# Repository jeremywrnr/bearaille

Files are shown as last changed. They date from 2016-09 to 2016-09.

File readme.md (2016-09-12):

:bear: bearaille
===============

This is Ruby, Arduino code, schematics, and designs for a braille keyboard
entrance device, using the RedBear Duo. Made for IDD at UC Berkeley, Fall 2016.

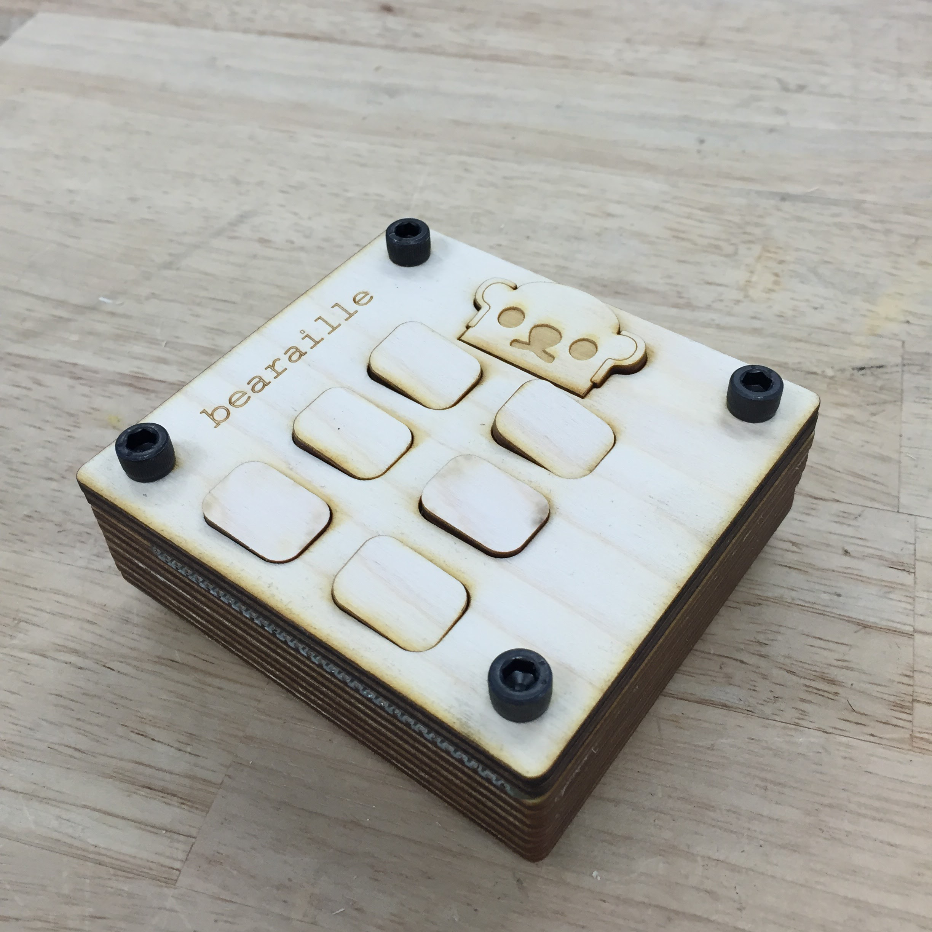
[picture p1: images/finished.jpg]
bearaille


## setup

To install ruby dependencies: `bundle`. The ruby keyboard workaround is only
neccesary because the redbear duo has an ARM processor which Arduino's standard
`Keyboard` library does not work. Ruby reads the serial monitor and converts
the text to keyboard input. You can open the serial port directly if you simply
want to verify that output is being sent from the arduino. To run this code,
you will have to set the proper port name to open in `serial.rb`. Once this is
done, and you checked that input is coming into the serial port, you can route
it to directly to the keyboard by running `make`.

## input device

I chose to base my project on Braille because it was a fairly concise input
method, and also would allow for people that were already familiar with how to
read braille an efficient way to enter text.

My device consists of 7 switches - one for each segment of the braille code,
and another for submitting and entering text, in the shape of a bear head. The
braille input mapping was based on [English braille][eng]. I use the internal
pullup resistors on each pin, so the pressing the switch makes the level `LOW`.
When the submit button is pressed, the state of each braille segment button is
read and recorded. There is an internal mapping in the arduino code which maps
each unique configuration to the string that it represents in English braille.
each switch when the enter button is pressed, and then returns a string which
corresponds to that mapping. This string is then sent to the over the Serial
line, which then is read by the ruby script and piped into a OSX keyboard
emulator.

This device is enclosed in a series of laser-cut layers, bound together by four
bolts. There is a perf board layer which holds the switches in place. These
switches were soldered in place, and then connected to wires for interfacing
with the RedBear in the board (depicted in pictures) below. These wires were
then fed into the appropriate pins on the breadboard.

[eng]:https://en.wikipedia.org/wiki/English_Braille

## reflection

I learned about designing phsyical enclosures, and also about emulating
arbitrary text as keyboard input on OSX. I was satisfied with the difficulty of
the project. It allowed me to experiment with laser cutting, and to be creative
with the internal mapping of text input. I made two protoypes before setting up
on the final design: the first didn't have any bear buttons, and the next
design added two new laser cut holes for securing the enclosure.

## videos

[youtube](https://youtu.be/5PIimpTt3YA)

[outtake](https://youtu.be/TLDJAm3al_s)

## schematic

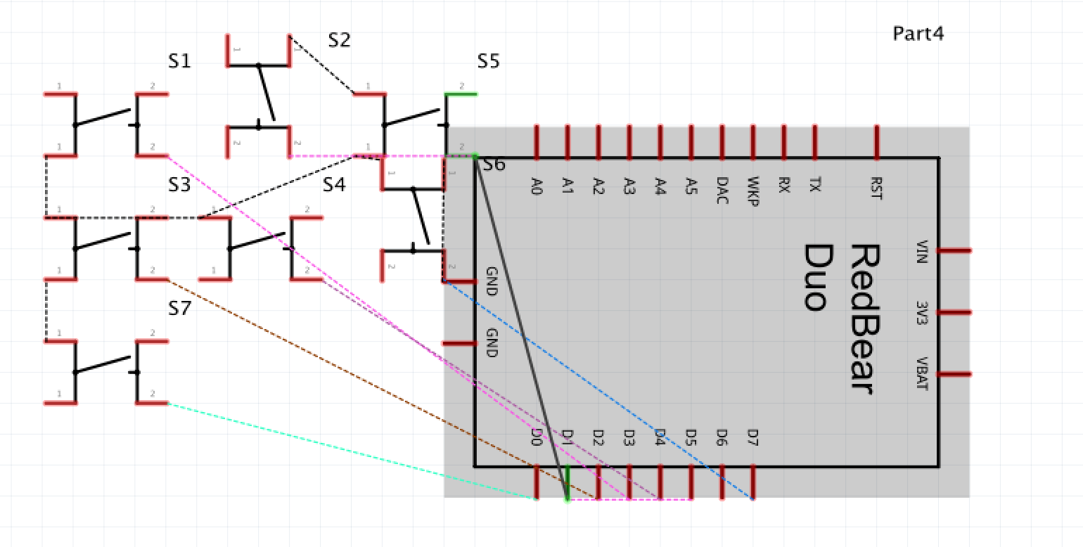
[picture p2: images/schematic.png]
schematic


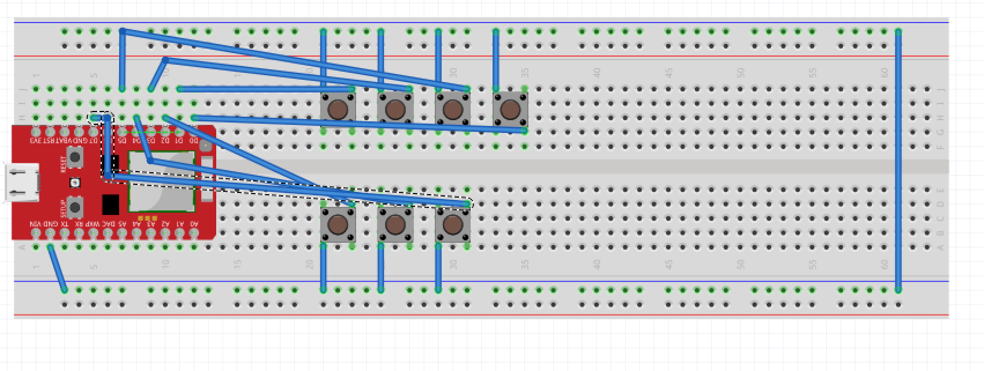
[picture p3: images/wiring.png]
wiring


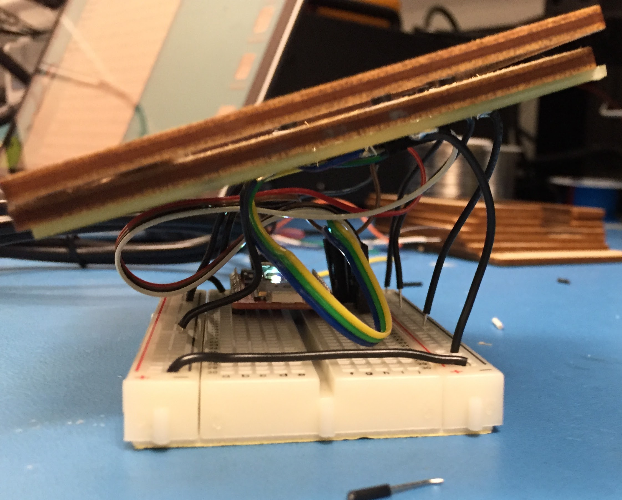
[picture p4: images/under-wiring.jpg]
under


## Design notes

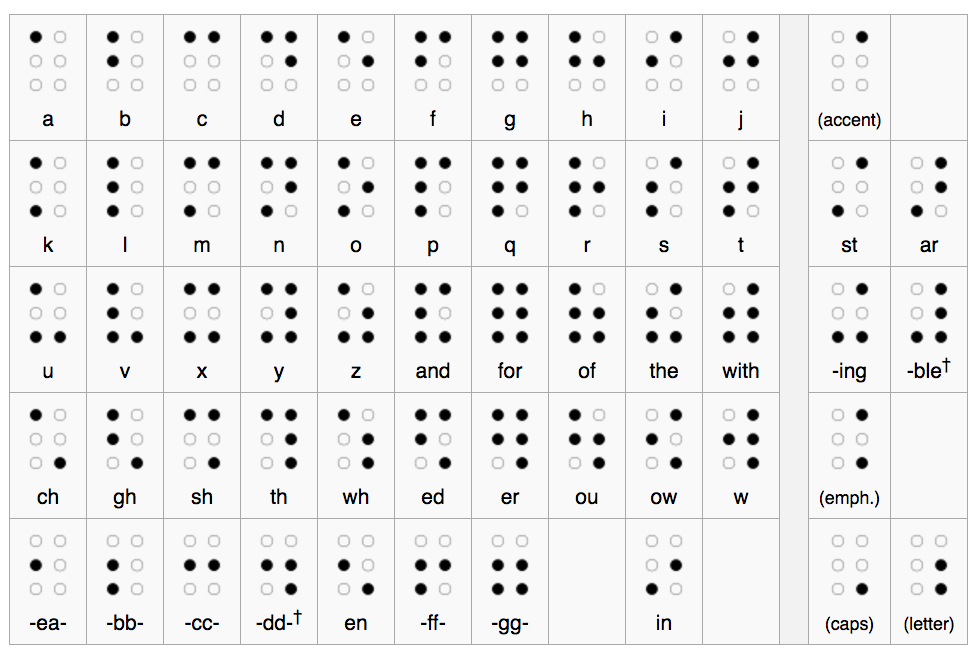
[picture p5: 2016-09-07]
images/braille.png

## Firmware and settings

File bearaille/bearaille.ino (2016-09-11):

/*
   Bearaille, by jeremy b warner
   MCU code to parse board signals as braille code
   Made at the University of California, Berkeley
   Interactive Device Design, Fall 2016
 */

int enter = D0; // submit
int br = D1; // lower-right
int bl = D2; // lower-left
int cr = D3; // center-right
int cl = D4; // center-left
int ur = D5; // upper-right
int ul = D6; // upper-left

// fix for readbear
#if defined(ARDUINO)
SYSTEM_MODE(SEMI_AUTOMATIC);
#endif

void setup() {
    // setup pin switches
    pinMode(enter, INPUT_PULLUP);
    pinMode(ul, INPUT_PULLUP);
    pinMode(ur, INPUT_PULLUP);
    pinMode(cl, INPUT_PULLUP);
    pinMode(cr, INPUT_PULLUP);
    pinMode(bl, INPUT_PULLUP);
    pinMode(br, INPUT_PULLUP);

    // begin communication
    Serial.begin(9600);
}

int encode() {
    // return intermediate evaluation code from switches
    int code = 0;

    /* ul, ur, cl, cr, bl, br */
    /* MSB <------------> LSB */
    if(digitalRead(ul) == LOW) code += 32;
    if(digitalRead(ur) == LOW) code += 16;
    if(digitalRead(cl) == LOW) code += 8;
    if(digitalRead(cr) == LOW) code += 4;
    if(digitalRead(bl) == LOW) code += 2;
    if(digitalRead(br) == LOW) code += 1;

    return code;
}

char* strmap(int code) {
    // return relevant braille encoding given encoding. range is between 0 - 63,
    // custom mapping based on simplified english braille. can be found here:
    // https://en.wikipedia.org/wiki/English_Braille
    switch(code) {
        case 0: return " "; // enter space
        case 1: return "???"; // caps mod
        case 2: return "the quick brown fox jumps over the lazy dog";
        case 3: return "null";
        case 4: return "null";
        case 5: return "???"; // letter mod
        case 6: return "in";
        case 7: return "null";
        case 8: return "ea";
        case 9: return "null";
        case 10: return "bb";
        case 11: return "null";
        case 12: return "cc";
        case 13: return "dd";
        case 14: return "ff";
        case 15: return "gg";
        case 16: return "???"; // accent mod
        case 17: return "???"; // emph mod
        case 18: return "st";
        case 19: return "ing";
        case 20: return "null";
        case 21: return "null";
        case 22: return "ar";
        case 23: return "ble";
        case 24: return "i";
        case 25: return "ow";
        case 26: return "s";
        case 27: return "the";
        case 28: return "j";
        case 29: return "w";
        case 30: return "t";
        case 31: return "with";
        case 32: return "a";
        case 33: return "ch";
        case 34: return "k";
        case 35: return "u";
        case 36: return "e";
        case 37: return "wh";
        case 38: return "o";
        case 39: return "z";
        case 40: return "b";
        case 41: return "gh";
        case 42: return "l";
        case 43: return "v";
        case 44: return "h";
        case 45: return "ou";
        case 46: return "r";
        case 47: return "of";
        case 48: return "c";
        case 49: return "sh";
        case 50: return "m";
        case 51: return "x";
        case 52: return "d";
        case 53: return "th";
        case 54: return "n";
        case 55: return "y";
        case 56: return "f";
        case 57: return "ed";
        case 58: return "p";
        case 59: return "and";
        case 60: return "g";
        case 61: return "er";
        case 62: return "q";
        case 63: return "for";
        default: return "null";
    }
}

void loop() {
    // trigger on submission
    if (digitalRead(enter) == LOW) {

        // read the code, get string
        char* in = strmap(encode());

        // write string
        Serial.write(in);
        Serial.write('\n');

        // slow down
        delay(200);
    }
}

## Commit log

2016-09-07 add default case
2016-09-08 adding enclosure designs
2016-09-09 adding enclosure
2016-09-11 adding schedmatic
    [bearaille.fzz]
2016-09-11 update images
    [bearaille.fzz]
